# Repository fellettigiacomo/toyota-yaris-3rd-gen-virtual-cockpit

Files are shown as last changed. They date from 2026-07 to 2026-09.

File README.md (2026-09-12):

# Toyota Yaris (3rd Gen / XP130) — Virtual Cockpit





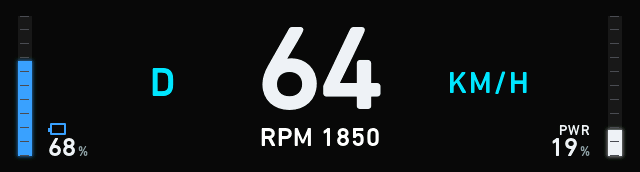
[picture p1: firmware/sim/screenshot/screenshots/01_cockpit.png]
Virtual Cockpit


A from-scratch digital instrument cluster for a 2014 Toyota Yaris Hybrid
(3rd gen / XP130, THS-II NoDSU), driven entirely by the car's own
**reverse-engineered CAN bus** — no dealer tools, no published DBC, no OEM
documentation.

The repository is divided into three main folders:

1. **Reverse-engineering** (`re/`) — a CAN bus sniffer and all the
   documentation, Python tooling and findings used to decode the bus
   signal by signal.
2. **CAN Database (DBC)** (`dbc/`) — the CAN Database with all the decoded
   signals and their translation formulas.
3. **3D Models** (`3d/`) — Fusion360 Project File and 3MF print files to 3d print the enclosure
4. **The dashboard** (`firmware/`) — an LVGL-based instrument cluster
   firmware that decodes the resulting DBC live and drives a physical
   display strip mounted in the car.

> **Safety note.** The firmware only ever *listens* to the vehicle's CAN bus
> (`TWAI_MODE_LISTEN_ONLY` — no transmit, no ACK, per the ESP-IDF driver
> contract). It cannot send commands to the car. That said, this taps a real
> vehicle's diagnostic bus: read the staged bring-up procedure in
> [`re/obd-capture-fw/README.md`](re/obd-capture-fw/README.md) before
> connecting anything to a running car.

## Screens

The cluster cycles through four screens either with the board's physical
**BOOT button**, or by **tapping anywhere on the panel** (presence-only
touch).

### 🏁 Cockpit

Speed, gear (or 0–50 / 0–100 accel timer), RPM/EV state, and two matching
vertical gauges flanking it: HV battery charge on the left, instantaneous
CHG/PWR power flow on the right.

Cockpit

### ⚡ Energy Flow

ENGINE / MOTOR / BATTERY / WHEELS and the four paths between them. Each link
is a dim shaft carrying a bright segment that travels the way the energy
does — red for the engine's mechanical drive, green for anything being
recovered, blue for the pack when it is the one giving.

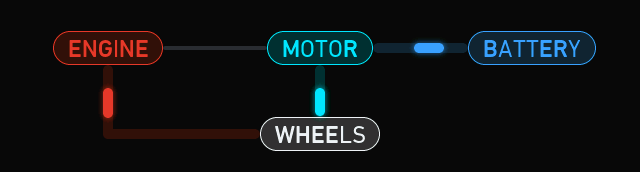
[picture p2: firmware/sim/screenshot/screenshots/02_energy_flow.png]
Energy Flow


### 📊 Efficiency

The session's EV-vs-engine split, drawn as a full-bleed divide of the whole
screen: the electric share fills from the left edge, the engine share holds
the rest, and both percentages hang off the seam between them. Distance and
average speed keep the bottom corners.

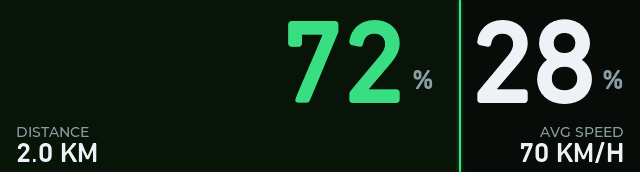
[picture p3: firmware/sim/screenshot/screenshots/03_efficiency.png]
Efficiency


### 📈 G-Meter

Longitudinal and lateral acceleration from the board's own QMI8658 IMU, on a
g-ball where the dot is the acceleration vector — up under power, down under
braking, sideways the way the car is turning — plus the session's four
directional peaks.

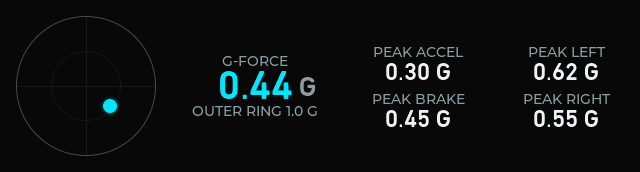
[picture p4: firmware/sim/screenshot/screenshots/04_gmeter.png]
G-Meter


## Hardware

- **Board**: Waveshare ESP32-S3-Touch-LCD-3.49 (ESP32-S3R8, 8 MB PSRAM,
  16 MB flash) — AXS15231B QSPI display, physical panel 172×640 portrait,
  rotated in software to a 640×172 landscape strip.
- **CAN transceiver**: SN65HVD230, wired to OBD-II pins 6 (CAN-H) / 14
  (CAN-L). Full wiring table and GPIO rationale in
  [`re/obd-capture-fw/README.md`](re/obd-capture-fw/README.md).
- **IMU**: the board's onboard QMI8658, on its sensor I2C bus (GPIO47/48,
  address 0x6B) — accelerometer only, for the G-meter screen. Nothing to
  wire: it is already on the board.

## Repository layout

```
.
├── dbc/                     # Reverse-engineered DBC (toyota_yaris_xp130_reversed.dbc)
├── firmware/                # Dashboard firmware (LVGL) + desktop simulator
│   ├── include/             #   board pins, VehicleState struct, LVGL config
│   ├── src/
│   │   ├── ui/               #   screens: cockpit_ui, energy_flow_ui, efficiency_ui, gmeter_ui
│   │   ├── can_decoder.cpp   #   DBC-driven CAN -> VehicleState decode
│   │   ├── imu.cpp           #   QMI8658 accelerometer (G-meter screen)
│   │   └── g_meter.cpp       #   IMU + CAN -> forward/lateral g, axes self-calibrating
│   └── sim/                 #   SDL2 desktop simulator, no board required
└── re/                      # Reverse-engineering workspace
    ├── obd-capture-fw/      #   ESP32-S3 passive CAN sniffer + SD logger
    ├── docs/                #   Signal reverse-engineering notes and findings
    ├── tools/               #   Python scripts used to reverse-engineer the bus
    └── data/logs/           #   Sample real-drive CAN captures (candump format)
```

## Building the dashboard firmware

Requires [PlatformIO](https://platformio.org/) (CLI or VS Code extension).

```sh
cd firmware
pio run                 # build
pio run -t upload       # flash
pio device monitor      # serial console @ 115200
```

No car handy? Build the `demo` environment instead — it sweeps `VehicleState`
with fake data and skips CAN entirely:

```sh
pio run -e demo -t upload
```

## Desktop simulator

Iterate on screen UI without any hardware, replaying a real drive log in an
SDL2 window (macOS, via Homebrew):

```sh
brew install sdl2 cmake
cd firmware/sim
cmake -B build
cmake --build build -j
./build/sim
```

Press SPACE to cycle screens, same as the board's BOOT button. Details and
known rough edges in [`firmware/sim/README.md`](firmware/sim/README.md).

## Building the CAN sniffer (`re/obd-capture-fw`)

```sh
cd re/obd-capture-fw
pio run
pio run -t upload
pio device monitor
```

Logs every frame to SD in `candump`-compatible text, and can stream the same
data live over USB (`STREAM ON` at the serial console) for capture straight
to a PC via `re/tools/usb_stream_logger.py`. Full bring-up order, wiring, and
safety steps in [`re/obd-capture-fw/README.md`](re/obd-capture-fw/README.md).

## Reverse-engineering workflow

1. Capture raw frames with `re/obd-capture-fw` → SD card, `candump` format.
2. Analyze with the scripts in [`re/tools/`](re/tools/) (`id_stats.py`,
   `byte_stats.py`, `decode_dbc.py`, `cross_validate_candidates.py`, …) or
   import into SavvyCAN / `python-can` / `cantools`.
3. Confirmed signals go into [`dbc/toyota_yaris_xp130_reversed.dbc`](dbc/toyota_yaris_xp130_reversed.dbc),
   with methodology and evidence in [`re/docs/signal_findings.md`](re/docs/signal_findings.md)
   and a quick-reference table in [`re/docs/decoded_signals_summary.md`](re/docs/decoded_signals_summary.md).
4. `firmware/src/can_decoder.cpp` decodes the same signals live on
   the dashboard.

Speed, RPM, gear, pedals, EV-drive, HV battery SOC, and the CHG/ECO/PWR
gauge are all confirmed on two independent real-drive logs. HV battery
current/voltage and remaining range are confirmed **absent** from this bus.

## Status

Hobby, single-vehicle reverse-engineering project — signal mappings may not
carry over to other trims/markets/model years. Parts of this repo have not
yet been compiled or run on real hardware (see the caveats in
`re/obd-capture-fw/README.md` and `firmware/sim/README.md`); expect to
iterate on first boot.

## Contributing

Issues and PRs are welcome, especially signal validation on other Yaris
Hybrid units — please note your model year/market if you're confirming or
contradicting a signal in `re/docs/signal_findings.md`.

## License

No license has been chosen yet.

## Acknowledgments

- [pioarduino/platform-espressif32](https://github.com/pioarduino/platform-espressif32)
- [lewisxhe/SensorsLib](https://github.com/lewisxhe/SensorsLib)
- [LVGL](https://lvgl.io/) 8.3
- Waveshare's official ESP32-S3-Touch-LCD-3.49 example code (display/board
  bring-up reference)

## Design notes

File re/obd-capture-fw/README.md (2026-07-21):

# obd-capture-fw

Firmware for the ESP32-S3 (Waveshare ESP32-S3-Touch-LCD-3.49) that passively
sniffs the Toyota Yaris Hybrid (3rd gen / XP130, 2014) OBD-II CAN bus, shows a
live "candump on screen" table on the built-in display, and logs every raw
frame to a microSD card in a format directly importable into SavvyCAN /
python-can / cantools for offline reverse-engineering.

This is step one of the larger virtual-cockpit dashboard project (`../../firmware/`):
Toyota does not publish a DBC for this vehicle, so nothing (EV mode, energy
flow, speed, etc.) can be decoded until the CAN IDs are reverse-engineered
from a capture -- this tool's only job is to capture everything so that can
happen afterwards on a PC.

## Hardware

- **Board**: Waveshare ESP32-S3-Touch-LCD-3.49 (ESP32-S3R8, 8MB PSRAM, 16MB
  flash, silkscreen "Rev1.1"). AXS15231B display (172x640, QSPI), PCF85063
  RTC, onboard microSD slot (SDMMC 1-bit).
- **CAN transceiver**: SN65HVD230 (3.3V, no level shifting needed).

### Wiring

| SN65HVD230 pin | Connect to |
|---|---|
| VCC | 3V3 (expansion header, right column) |
| GND | G (expansion header, right column) |
| TX  | GPIO1 |
| RX  | GPIO2 |
| RS  | GND (always high-speed mode) |
| CANH | OBD-II pin 6 |
| CANL | OBD-II pin 14 |
| (car GND) | OBD-II pin 4 or 5 |

**Important:**
- Leave the SN65HVD230 breakout's onboard 120-ohm termination jumper **open
  / disabled**. The vehicle's CAN bus is already terminated at both ends;
  adding a third 120-ohm resistor degrades signal integrity.
- GPIO1/GPIO2 were chosen from the 22-pin expansion header pins confirmed
  present on this board's silkscreen (0, 1, 2, 3, 4, 5, 19, 20, 38, 39, 40,
  41, 43, 44). Avoided: **GPIO0/3** (boot strapping -- GPIO0 is already wired
  to the BOOT button), **GPIO19/20** (native USB D-/D+ -- this is the same
  USB-C port used for flashing and the serial monitor; wiring anything else
  to these pins conflicts electrically with the USB PHY and will break USB
  communication), **GPIO39/40/41** (used internally by the onboard SD card
  slot), **GPIO43/44** (UART0 / USB-serial bridge), and **SDA/SCL** (GPIO47/48,
  already used internally for the RTC/IMU I2C bus -- also electrically
  incompatible with the transceiver's TX/RX signaling even if it were free).
  GPIO4/GPIO5 are an equally valid alternative pair (also on the header's
  right column) if GPIO1/2 turn out to be inconvenient to wire.
- All onboard peripheral pins (display, RTC, SD) in `include/board_pins.h`
  were extracted directly from Waveshare's own official example code
  (`github.com/waveshareteam/ESP32-S3-Touch-LCD-3.49`), not guessed.

### Physical stop-capture control

There's no touchscreen UI in this tool -- the physical **BOOT button** on the
board is used to safely close the current capture session and start a new
one (drains the SD write queue, closes the file cleanly, writes a `.meta`
sidecar). Touch was intentionally skipped here to avoid depending on the
AXS15231B's proprietary touch protocol for a tool whose only real job is
logging; touch/LVGL is reserved for the later dashboard project.

## Building

Requires [PlatformIO](https://platformio.org/) (CLI or VS Code extension).

```
cd re/obd-capture-fw
pio run              # build
pio run -t upload    # flash
pio device monitor   # serial console (115200 baud)
```

The project uses the [pioarduino](https://github.com/pioarduino/platform-espressif32)
community platform instead of the official PlatformIO `espressif32` platform,
because it ships arduino-esp32 3.x (IDF5-based), needed for the QSPI
`quad_mode` support in `esp_lcd_panel_io_spi_config_t` that the display
driver uses (see `src/WAVESHARE_VENDORED.md`). The official registry
platform was still pinned to an older arduino-esp32 2.0.x core at the time
this was written.

The display is driven via ESP-IDF's `esp_lcd` component and Waveshare's own
panel driver (ported verbatim into `src/axs15231b/`, `src/touch/` -- see
`src/WAVESHARE_VENDORED.md`), the same fix `../../firmware/` uses for the
same panel -- not `GFX Library for Arduino`'s own AXS15231B panel driver,
which produces flicker/split-screen/black-line corruption on this panel over
QSPI (see `src/display_ui.cpp`'s header comment). `GFX Library for Arduino`
is still a dependency, but only for its headless `Arduino_Canvas`
(RAM-only framebuffer + bitmap-font text rendering).

This firmware has **not yet been compiled/tested on real hardware** -- it was
written against Waveshare's official example code and the documented APIs of
`driver/twai.h`/`esp_lcd` (ESP-IDF), `GFX Library for Arduino`, and
`SensorLib` (`lewisxhe/SensorsLib`, the same RTC library Waveshare's own
demos use), but please build it yourself and watch the serial monitor
closely on first boot.

## Setting the clock

The board has no GPS/network time source. Log timestamps use monotonic
`esp_timer_get_time()` deltas regardless, but the *absolute* time in each
session's filename and candump timestamps comes from the onboard PCF85063
RTC, which needs to be set once. Over the serial monitor:

```
SETTIME <unix_epoch_seconds>
```

If the RTC has never been set, sessions still capture correctly, just with
timestamps relative to the ESP32's own boot time (filenames get a
`RTCUNSET` tag instead of a date, and each `.meta` file records
`rtc_valid=0`).

## Live USB streaming (debug / new-feature work without pulling the SD card)

In addition to logging to the SD card, every captured frame can be streamed
live over the same USB-CDC port used for flashing/the serial monitor, in the
same candump text format as the `.log` files. This is a separate fan-out
from `canRxTask` (own queue, own task, see `usb_stream.cpp`), so a slow or
absent PC-side reader can never affect SD logging or drop frames from the
capture.

Over the serial monitor:

```
STREAM ON    # raw candump lines start flowing over the port
STREAM OFF   # back to the normal [status]/[main]/... console output
```

While streaming is on, the periodic `[status]` line is suppressed so the
port carries pure candump lines; occasional other firmware messages (e.g. a
bus-off warning) can still interleave, so anything reading the stream should
just ignore lines that don't match the candump shape.

To capture straight to a file on a PC, use
[`../tools/usb_stream_logger.py`](../tools/usb_stream_logger.py)
(`pip install pyserial`):

```
python3 ../tools/usb_stream_logger.py /dev/ttyACM0
python3 ../tools/usb_stream_logger.py /dev/ttyACM0 ../data/logs/bench_test.log --settime
```

It sends `STREAM ON`, writes every valid candump line to the output file
(filtering out any non-candump firmware messages), and sends `STREAM OFF` +
closes cleanly on Ctrl+C. The resulting file is byte-for-byte the same
format as an SD `.log`, so it drops straight into `../tools/parse_log.py`,
SavvyCAN, `python-can`, or `cantools`.

## Bring-up order (do this in order, do not skip ahead)

1. **Display/SD/RTC only.** Flash and check the serial monitor + screen with
   nothing connected to GPIO1/2 yet. Confirm the stats bar renders, the SD
   card mounts (`SD:` shows free space instead of `NONE`), and the RTC
   responds.
2. **CAN bench test, no vehicle.** Wire the SN65HVD230 to GPIO1/2 (RS to
   GND, termination jumper open) but do **not** connect CANH/CANL to the car
   yet. The TWAI driver runs in `TWAI_MODE_LISTEN_ONLY` -- per the ESP-IDF
   documentation this mode does not transmit or ACK anything on the bus, so
   it is safe to bring up in isolation. Confirm no bus errors are reported
   with nothing connected.
3. **Ignition-accessory only, engine off.** Connect CANH/CANL to OBD-II pins
   6/14 (and ground to pin 4 or 5). Before powering the transceiver, check
   with a multimeter that the bus looks sane (idle CAN-H/CAN-L both settle
   near 2.5V; do this with the transceiver disconnected). Turn the key to
   accessory/on (engine off) and watch the error/bus-off counters on the
   stats bar closely for the first few minutes.
4. **Engine running.** Only once step 3 looks clean, start the engine and
   let a full capture session run.
5. **Stop and pull the card.** Press BOOT to cleanly close the session, then
   remove the SD card and import `/CANLOGS/session_NNNN_*.log` into SavvyCAN,
   `python-can`, or `cantools`.

## Log format

Each `.log` file is plain SocketCAN-`candump`-compatible text, one frame per
line:

```
(1720098765.123456) can0 1d0#0011223344556677
```

- Timestamp: seconds.microseconds (RTC epoch + monotonic delta if the RTC is
  set, otherwise relative to boot).
- `can0` is a literal label (not tied to actual wiring) -- this is what
  generic candump-log importers expect.
- CAN ID: lowercase hex, zero-padded to 3 digits (standard/11-bit) or 8
  digits (extended/29-bit).
- Data: lowercase hex, 2 characters per byte, byte count implied by DLC.
- RTR frames are logged as `id#R` with no data bytes.

A sidecar `.meta` file (same base name) holds session metadata (frame count,
bus-error/bus-off counts, RTC validity, bitrate) -- deliberately **not**
inlined into the `.log` file, so the log stays 100% strict-format and safe
to feed straight into SavvyCAN/python-can/cantools without pre-processing.

## Notes / known limitations

- **No second CAN node was available to test the listen-only mode's
  passivity** (e.g. by deliberately inducing a bus error and watching for any
  dominant bits with a scope). The firmware relies on `TWAI_MODE_LISTEN_ONLY`
  behaving exactly as ESP-IDF documents it (fully passive, no ACK, no
  transmission). Do the ignition-accessory-only bring-up step above before
  ever running with the engine on, and stop immediately if bus errors climb.
- Data written since the last periodic `fsync` (every 5s, see
  `SD_SYNC_INTERVAL_MS` in `include/app_config.h`) can be lost on abrupt power
  loss. Always use the BOOT button to stop a session cleanly before
  disconnecting power.
- Bus load % is an approximation (fixed ~47 bits of framing overhead per
  frame, ignoring CAN bit-stuffing).
- This firmware has not been compiled yet (see "Building" above). The display
  driver was ported from `../../firmware/`'s already-hardware-verified
  `esp_lcd`-based approach (see `src/display_ui.cpp`'s header comment), but
  that specific port has not itself been tested on this project's hardware --
  watch the panel closely on first boot.

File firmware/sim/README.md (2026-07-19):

# Desktop simulator

Runs the real cluster UI (`src/ui/*`) in an SDL2 window on your Mac, fed by
the same real-drive-log replay the `pio run -e demo` firmware build uses
(`can_decoder.cpp` + `demo_log_data.cpp`, unmodified) -- no ESP32 board, no
flashing. It does **not** exercise `display_driver.cpp` or anything
ESP-IDF/hardware-specific; that stays firmware-only. The BOOT-button screen
switch (`screen_nav.cpp`) is simulated via the spacebar, and the panel's
tap-anywhere touch switch (`touch_nav.cpp`) via a left click anywhere in
the window.

## Build

```sh
brew install sdl2 cmake
cd firmware/sim
cmake -B build
cmake --build build -j
./build/sim
```

First build takes a little longer since CMake fetches LVGL 8.3.11 from
GitHub (same version `platformio.ini` pins for the firmware).

If `cmake -B build` can't find SDL2 (rare, usually only if Homebrew isn't on
your default `PATH`/`CMAKE_PREFIX_PATH`), retry with:

```sh
cmake -B build -DCMAKE_PREFIX_PATH=$(brew --prefix)
```

## Use

- Press SPACE, or click anywhere in the window, to cycle screens -- the
  spacebar stands in for the board's BOOT button (GPIO0), the click for a
  tap on the touch panel, both drive the same cycle on real hardware.
- The drive log loops automatically (~5.7 minutes/lap) and includes real
  EV/regen/charge/cruise/kick-down transitions, so the energy-flow arrows
  should visibly change direction and color as it plays.
- Close the window (or Cmd+Q) to quit.

## Caveat

This was written and reviewed by hand against LVGL 8.3's documented API and
this repo's own `display_driver.cpp` (for the LVGL display-driver wiring)
but was **not compiled or run** in the environment it was written in (no
SDL2/CMake toolchain, no Mac, no display available there). If `cmake`/the
build fails, that's expected to be entirely fixable -- it just hasn't been
exercised yet. The most likely rough edges, in rough order of likelihood:

- The `LV_CONF_PATH`/`LV_CONF_INCLUDE_SIMPLE` wiring in `CMakeLists.txt` was
  checked against LVGL's actual `env_support/cmake/custom.cmake` for v8.3.11,
  not assumed -- but CMake variable-scoping subtleties around
  `FetchContent_MakeAvailable` are exactly the kind of thing that looks right
  on paper and isn't.
- `SDL_PIXELFORMAT_RGB565` streaming-texture support should be universal on
  macOS's default (Metal-backed) SDL2 renderer, but hasn't been confirmed.

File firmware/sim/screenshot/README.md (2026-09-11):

# Screenshot renderer

Regenerates the screenshots the top-level README shows, straight from the real
LVGL UI — no SDL, no window, no board. Every pixel comes out of the same
`build()` / `update()` the firmware calls, so these frames are the cluster,
not a mockup of it.

```sh
cd firmware/sim/screenshot
./render.sh
```

That builds, plays the scenes, and writes `screenshots/*.png` at the panel's
native 640×172.

**It takes a couple of minutes**, most of it the efficiency scene. The UI
modules integrate against `millis()`, so the scenes run in real time rather
than fast-forwarded — and the efficiency screen's EV share is weighted by
distance, so the only way to reach a given split with a plausible trip behind
it is to actually drive the distance.

## What gets rendered

| File | Scene |
|---|---|
| `01_cockpit.png` | 64 km/h in D, engine running, 68% SOC, 19% PWR |
| `02_energy_flow.png` | Hybrid drive — engine to the wheels, pack assisting through the motor, one link idle |
| `03_efficiency.png` | ~2 km covered, 72% of it electric |
| `04_gmeter.png` | Trail-braking into a right-hander, after a drive that fills the peaks |

## Notes on the scenes

The scenes are scripted `VehicleState` sequences, not canned frames, so they
have to satisfy the same logic the car does:

- **The cockpit is rendered first, and never from a standstill.** `AccelTimer`
  arms itself at zero speed, so a scene that jumped from 0 to 64 km/h would
  latch a bogus 0–50 result and replace the gear letter with it.
- **The G-meter scene has to earn its axes.** `screenshot.cpp` provides its own
  `Imu::` rather than linking `src/imu.cpp`, and it deliberately does *not*
  hand the calibration pre-aligned axes: it synthesizes what a real
  accelerometer would have measured and rotates it through an arbitrary
  mounting (yaw 35°, pitch 20°, roll 10°). The scene then drives a standstill,
  a launch, braking and both corners so `g_meter.cpp` can find level, learn
  which way is forward, and fill the peak tiles — exactly as it would in the
  car.
- **Screens are cycled through the real BOOT-button path**, debounce included,
  rather than by reaching into `AppUi`'s internals.

This is why the renderer is worth having beyond documentation: it exercises
the parts that are otherwise only testable in a moving car. It has already
caught a real bug — the G-meter's level capture was being tilted by braking to
a halt, which showed up here long before the code reached a vehicle.

## Requirements

CMake ≥ 3.16, a C++17 compiler, and Python 3 (standard library only — the
converter uses `zlib` and `struct`). LVGL 8.3.11 is fetched automatically,
the same version `platformio.ini` pins for the firmware and `../CMakeLists.txt`
uses for the simulator.

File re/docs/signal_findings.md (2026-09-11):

# Toyota Yaris Hybrid XP130 (2014, THS-II NoDSU) — CAN bus signal findings

Full methodology and validation evidence behind the signals in
[`toyota_yaris_xp130_reversed.dbc`](../../dbc/toyota_yaris_xp130_reversed.dbc).
For a compact table, see [`decoded_signals_summary.md`](decoded_signals_summary.md).

## Capture setup

- **Tap point**: the factory head-unit connector (28-pin, p/n `90980-12555`),
  pins 9 (CAN-H) / 10 (CAN-L), 500 kbps — **not** the OBD-II diagnostic port.
  This is the same point where the aftermarket Simplesoft CAN-bus box
  normally taps in; the message set seen here (`SPEED`, `RPM`, `GEAR`,
  `BRAKE`, `TURN_SIGNALS`, `ODOMETER`, …) matches what's expected on the
  main HS-CAN bus, so this connector is treated as the same logical bus, not
  a separate/richer one.
- **Logs**: two independent real-drive captures, `session_0044.log` (~430s,
  ESP32 in place of the Simplesoft box) and `session_0047.log` (~440s, ESP32
  inline between the Simplesoft box and the car). A signal is only marked
  "confirmed" once its behaviour reproduces on both.
- **Reference DBCs**: `toyota_nodsu_hybrid_pt_generated.dbc` from
  `BogGyver/opendbc` (branch `tesla_unity_dev`), cross-checked against the
  Prius/Camry/Highlander hybrid variants and `commaai/opendbc` upstream.
  None of these define SOC, range, or fuel — those come from Prius-community
  reverse-engineering docs (EAA-PHEV wiki, PriusChat) and original analysis.
- **Toolchain**: the scripts in [`../tools/`](../tools/) plus `cantools` for
  strict DBC-based decoding. `cross_validate_candidates.py` and
  `find_word16_candidates.py` implement the cross-log check described above.

## Confirmed signals

| Signal | ID | Field | Formula |
|---|---|---|---|
| Gear (P/R/N/D/B) | `0x127` | `GEAR` | 4-bit enum, byte5 high nibble |
| Vehicle speed | `0x0B4` | `SPEED` | `(byte5<<8\|byte6) * 0.01` km/h |
| Engine RPM | `0x1C4` | `RPM` | signed 16-bit `* 0.78125` rpm |
| Accelerator pedal | `0x245` | `GAS_PEDAL` | `byte2 * 0.005` (0–1 = 0–100%) |
| ICE running (bit) | `0x245` | `ICE_RUNNING` | byte3 bit4 |
| Brake pressed (bit) | `0x230` | `BRAKE_PRESSED` | single bit |
| Turn signals | `0x614` | `TURN_SIGNALS` | 2-bit enum + hazard bit |
| Odometer (total) | `0x611` | `ODOMETER` | 20-bit, km/miles unit flag |
| Ambient temperature | `0x442` | `AMBIENT_TEMP` | `byte0 - 40` = °C |
| HV battery SOC | `0x4A7` | `BATTERY_SOC` | `byte2 * 0.5` = % |
| EV drive (bit) | `0x498` | `EV_DRIVE` | byte5 bit7 |
| CHG/ECO/PWR indicator | `0x247` | `HSI_VALUE` / `HSI_ZONE` | see below |

**Gear** — validated across both logs: session_0044 shows a clean
P(0)→R(1)→D(3) sequence with `SPEED` and `BRAKE_PRESSED` transitions lining
up exactly with each shift; session_0047 adds N and a full end-of-drive
cycle through all five states including B (Engine Brake). `CAR_MOVEMENT`
(byte4 of the same message, signed, oscillates ±) is a separate field, not
part of the gear value.

**Speed / RPM** — inherited from opendbc, reconfirmed with `cantools`
against real 0→60→0 kph and idle/rev profiles. `WHEEL_SPEEDS` (0x0AA) from
opendbc is not present on this bus.

`SPEED`'s 0.01 kph scale is cross-validated against the odometer, which is
the one distance reference on board that regulation requires to be
*accurate* (unlike the speedometer — see below). Taking the exact instants
`0x611`'s `ODOMETER` ticks over a whole kilometre, the interval between the
first and last tick in session_0044 is exactly 2 km; integrating the decoded
`0x0B4` speed over that same interval gives 2.0001 km, i.e. **+0.01%**. The
method's own uncertainty is ±0.82%, set by `0x611`'s 1 Hz rate (each tick's
instant is only known to ±1 s). session_0047 never crosses two whole-km
boundaries, so no exact interval can be isolated there.

**Indicated vs. true speed** — the car's own speedometer reads *higher* than
`SPEED`: roughly +10 km/h at an indicated 140 against a true 130 on the
vehicle this was developed on (a single needle reading, so call it +5..+15).
This is deliberate and regulatory, not a decode error. UNECE R39 requires
that the indicated speed never be *lower* than the true speed and caps the
excess at 10% + 4 km/h, so manufacturers bias the cluster upward to stay
compliant across tyre wear, optional tyre sizes and temperature. At a true
130 km/h the legal window is 130–147.

The biased value is computed inside the instrument cluster and is **not**
broadcast: no field on this bus carries it. Four independent speed-carrying
fields all agree with `0x0B4` to within 0.5% across the full 0–63 km/h range
the logs cover — `0x2A4` byte[0:2] (Δ mean 0.00 km/h), `0x610` byte[2]
(1.0001×kph, R²=0.9996) and `0x498` byte[3] (0.9951×kph, R²=0.9957) — and
the odometer check above anchors the scale absolutely. A GPS comparison on
the road matches the decoded value as well.

No correction is applied in firmware, on purpose: `SPEED` is the true speed,
which is what the odometer, GPS and the other bus fields all agree on.
Matching the cluster instead would mean modelling its bias (`indicated =
k × true + c`), and on this car the cluster is an **analog needle** — a
driver reads it to ±3 km/h at best, and any photo-based calibration is
dominated by a systematic parallax error that repeating measurements cannot
average away. Chasing a ~5% correction whose own uncertainty is a few km/h
would add error rather than remove it.

**Accelerator / ICE running** — `GAS_PEDAL` ranges 0–35% observed, tracking
the accelerate/coast pattern of city driving. `ICE_RUNNING` agrees with
`RPM > 50` 98–99% of the time across both logs and is cleaner (no threshold
tuning needed).

**Brake pressed** — transitions line up exactly with gear shifts and speed
changes (brake held at standstill around each shift).

**Turn signals** — all three states (left/right/none) observed with
multi-second durations consistent with real indicator usage.

**Odometer** — confirmed as the *total* odometer (99552→99555 km over the
log), not remaining range; `UNITS` flag correctly reads km.

**Ambient temperature** — the only near-constant byte in the low-frequency
climate message family (`0x440`/`0x442`/`0x44D`/`0x45C`); raw values differed
between the two capture days (77 vs 67 → 37 °C vs 27 °C) and the scale was
confirmed against the actual outside temperature on each day. This is
outside air temperature, not engine/coolant temperature.

**HV battery SOC** — byte[2] of `0x4A7`, range 108–143 raw → 54.0–71.5%,
matching the real THS-II NiMH operating band (~40–80%). A SOC is the
*integral* of power flow, so it barely correlates with the accelerator at
zero lag; it was found by scoring each value *change* against expected
battery physics instead (discharge during EV driving, charge during ICE-on
or regen) rather than by instantaneous correlation. Physics checks out on
both logs: flat while parked, steady climb during stationary ICE warm-up
charging, slow decline through every EV stretch, recovery through every
ICE-on/regen stretch, never wraps. The 0.5%/bit scale matches the known
Techstream/Prius-Gen2 convention but has not been checked against a
reference tool reading.

**EV drive** — byte5 bit7 of `0x498`. On only while the vehicle moves with
the ICE stopped (pure electric propulsion); off at standstill even with the
ICE off, and off while driving with the ICE running. Matches the dash EV
indicator's semantics exactly (100% agreement with the moving+ICE-off state
across both logs). Two redundant "ICE stopped" bits were also found:
`0x49C` byte5 bit6 and `0x4AD` byte3 bit6.

**CHG/ECO/PWR indicator (Hybrid System Indicator)** — the gauge needle
position is broadcast directly on `0x247` (42.5 Hz, companion message to
`GAS_PEDAL`), no synthesis needed. `HSI_VALUE` (byte1) is the needle
position in percent of scale: 0 at standstill, +30..+47 at steady cruise
(the test that rules out this being just a copy of accelerator demand —
cruise needs sustained power even with a near-zero acceleration signal),
up to +86/+94 under moderately hard acceleration, negative while
coasting/braking with a hard clamp at exactly -100 (full CHG). `HSI_ZONE`
(byte0) carries the sign (12=drive/positive, 15=charge/negative,
4=zero-in-gear, 6=P/R). `HSI_GEAR_FLAG` (byte2) is 50 in forward gears,
255 in P/R.

**The sign lives in `HSI_ZONE`, not in `HSI_VALUE`'s byte.** The two sides
of the gauge use different encodings of byte1 and their raw ranges overlap,
so the byte on its own is ambiguous:

| Zone | Meaning | byte1 encoding | Raw seen in logs |
|---|---|---|---|
| 12 | ECO/PWR (positive) | unsigned magnitude, sweeps past 155 | 0–94 |
| 15 | CHG (negative) | two's complement, clamped at -100 | 156–255 (= -100..-1) |
| 4 | zero in gear | always 0 | 0 |
| 6 | P/R, gauge inactive | always 0 | 0 |

The zone/value correlation is exact across both sessions (n=32779, zero
exceptions), which is what makes it usable as the sign source. An earlier
firmware revision instead inferred the sign from byte1 alone (raw≥156 ⇒
negative, anchored on the confirmed CHG floor). That works for everything
in these two calm-driving logs but breaks on the car under full throttle:
the PWR sweep runs past 155, so a hard-PWR raw was read as a large negative
and the bar swung to CHG. On-car testing confirmed the flip; the decoder
now branches on `HSI_ZONE`.

**The four-zone table above describes the logs, not the encoding.** A later
on-car drive with hard acceleration reported `HSI_ZONE` values of 8, 9 and
14 as well — driving neither capture session contains. So 4/6/12/15 is
exhaustive for these logs and incomplete for the car, and what byte0 encodes
beyond the sign is still open. The firmware therefore reads *every* zone but
15 as an unsigned positive magnitude (15 being the only zone ever observed
carrying a negative value) rather than falling back to the DBC-nominal
signed read, and carries a temporary byte0 survey — frame count and raw
min/max per zone, dumped over serial when it learns something new — to be
removed once the encoding is known and the zones can be listed explicitly.

On the display, the PWR side is shown halved (`PWR% = raw/2`) because the
ECO/PWR boundary (raw≈100) is only the midpoint of the real gauge's PWR
sweep, not its top — so full PWR ≈ raw 200 reads 100%. That the raw value
does climb past 155 under full throttle (rather than clamping at +100 like
the CHG side does at -100) is exactly what the false-CHG flip demonstrated,
and it is consistent with this halved scaling.

## Strong hypotheses (semantics solid, exact scale unconfirmed)

| Signal | ID | Field | Notes |
|---|---|---|---|
| Brake pedal (analog) | `0x224` | `BRAKE_VALUE` | 16-bit, strongly correlated with the brake bit |
| Coolant temperature | `0x618` | `TEMP_RAW` | warm-up curve to plateau; scale guess `*0.375` ≈ 90 °C |
| Second temperature (oil/CVT/HV pack?) | `0x3B9` | `TEMP2_RAW` | correlates with elapsed time and coolant temp |
| Longitudinal accel/torque demand | `0x320` | `ACCEL_DEMAND` | signed, positive on acceleration, negative on braking/coast |
| Fuel consumption counter | `0x3A0` | `FUEL_COUNTER_RAW` | decrements with ICE-on runtime, **not** a tank-level gauge |

**Brake analog value** — byte[4:6] of `0x224` (~41 Hz, same rate as
`SPEED`/`BRAKE_PRESSED`, likely the same ECU). Median 0 while released vs.
median 62 while pressed (n=12027/5731); 99.99% of released samples are ≤5,
84% of pressed samples are >5. A single release event shows a smooth
continuous decay over ~700 ms, consistent with an analog pressure or pedal
position rather than a second bit. Exact units and full-scale range are not
confirmed (max observed 537, slightly above the 0–511 9-bit range opendbc's
unrelated `BRAKE_MODULE`/0x226 template would suggest — that ID is absent
from this bus).

**Coolant temperature** — byte[3] of `0x618`, part of a low-frequency
(~0.1 Hz) "combination meter" message family (`0x610`-`0x615`,
`0x618`-`0x61C`). Climbs from 0 at cold start to a plateau around 230–240 by
t≈350–430s, matching a textbook engine coolant warm-up curve reaching
thermostat-regulated temperature after ~5 minutes. `temp_C ≈ raw * 0.375`
places the plateau at a plausible 90 °C but is an unverified guess, not a
reference-thermometer calibration; could equally be transmission/CVT fluid.

**Second temperature signal** — byte[0] of `0x3B9` (dlc=3, only this byte
active, ~1 Hz). Climbs smoothly to a plateau late in the drive on both logs,
correlating strongly with elapsed time (r=0.945/0.968) and with the coolant
curve above (r=0.950/0.969), including a shared inflection point. Weak
correlation with instantaneous RPM (r≈-0.1) rules out a fast-responding
sensor and points to a larger thermal mass — candidates: engine oil,
CVT/transaxle fluid, or HV battery pack. Plateau value differs between the
two logs (173 vs 160), unlike a thermostat-regulated coolant signal, which
fits a less tightly-regulated mass. No scale proposed.

**Longitudinal accel/torque demand** — byte[4] of `0x320` (signed, ~20 Hz):
positive under acceleration (+10..+31 with pedal), negative while
braking/coasting (-8..-48), ~0 at rest and at steady cruise — this last
point is what rules it out as HV battery current, since current should stay
nonzero at cruise. byte[7] is the same signal with a constant +42 offset;
byte[5] is a `{0,8}` flag active only at standstill. Scale unconfirmed
(plausible ~0.02–0.05 m/s² per LSB).

**Fuel consumption counter** — byte[7] of `0x3A0`, the only active byte in
an otherwise all-zero message, 10 Hz. Decrements track ICE-on runtime
(~1 unit per 20–25s of engine running, consistent to ~7% across both logs),
not wall-clock time or distance, which rules out both "fuel level" (a 36 L
tank on this scale would imply an impossible 50+ L/h burn rate) and
"distance to empty". Best read as a high-resolution fuel-consumed counter,
quantum ≈10–30 mL — most likely the low byte of a wider register, since a
wrap 255→0 has not yet been observed (would need a ≥30 min log to confirm).
Use it for instantaneous consumption, not as an absolute level.

## Present but not independently validated

Inherited from opendbc at their documented layout; message exists at the
expected ID but the specific bits were not exercised during capture:

- `0x620 SEATS_DOORS` — door open / seatbelt bits (seatbelt toggled 0/1;
  doors never opened during the drive)
- `0x622 LIGHT_STALK` — headlight/fog/auto-high-beam bits (low
  beam/parking light toggled, plausible)
- `0x399 PCM_CRUISE_SM` — cruise control state (all-zero, never engaged)
- `0x3B7 ESP_CONTROL` — traction/VSC disable, brake lights (all-zero, no
  VSC/TC intervention during this calm drive)

## Ruled out

Documented so these aren't re-investigated:

- **`0x4A8` byte2 top-3-bits** — looked like a battery-bar level; it's a
  cyclic counter that wraps every 60–100s, physically incompatible with an
  HV battery.
- **`0x4A2` byte3/byte5** (`CHASSIS_BRAKE2`) — anti-correlates with the
  accelerator/braking pattern strongly enough to look like battery power at
  first, but correlates even more strongly with the confirmed brake analog
  signal (`0x224`) and with `SPEED` (which battery power shouldn't track) —
  almost certainly a second ABS/VSC brake telemetry pair, not SOC.
- **`0x612` byte5, `0x619` byte6, `0x63B` byte6** — unstable trends whose
  correlation sign flips between the two logs, or fixed-period counters
  (`0x63B` increments every ~25.5s regardless of driving state) — heartbeat/
  counter artifacts, not physical signals.
- **`0x4AC` byte6** — free-running 4.5s-on/4.5s-off square wave (9.0s
  period), present identically in every log. Not an event/status signal.

## Confirmed absent from this bus

Not obtainable by passive listening on this connector:

- **Remaining driving range (km)** — only the total odometer exists;
  likely computed inside the instrument cluster and never broadcast.
- **HV battery current / voltage / temperature** — no broadcast found;
  the Prius-style diagnostic IDs (`0x03B`/`0x3CB`/`0x529`) are absent on
  this platform. Would require solicited UDS requests to the battery ECU.

## Architecture notes

Signals `0x498`–`0x4AF` are an undocumented Toyota hybrid-powertrain
telemetry family — opendbc's `toyota_2017_ref_pt.dbc` names the same ID
range `ENG1D50`..`ENG1D60`, opaque data-recorder frames from the `CGW`
(Central Gateway) node, absent on non-hybrid Toyota models. This is where
SOC and hybrid status live. With SOC, EV-drive, ICE-running and the HSI
power-demand signal, the aftermarket Simplesoft box's "OilElectricityInfo"
energy-flow display (3-bit battery level, hybrid flag, 6 flow-direction
flags) can be fully reconstructed from passive listening alone — no active
diagnostic polling needed, despite the ~10s the box's screen takes to load
(most likely just app initialization, not a diagnostic round-trip).

## Open questions

1. **SOC scale** (`0.5%/bit`) is a known Toyota/Techstream convention, not
   yet checked against a reference tool reading.
2. **Fuel counter wrap** (`0x3A0` byte7) — needs a ≥30 min log to observe
   the predicted 255→0 rollover and confirm it's the low byte of a wider
   register.
3. **`0x612` byte5** — a slow random walk centered on 128 (±16) with a
   byte1 heartbeat bit; excluded as SOC (no charge/discharge physics) but
   not identified. Possibly 12V-battery current with an offset. Low
   priority.
4. **`0x4AE` byte7** — rises slowly (72→75) in both logs; a weak,
   unconfirmed candidate for HV battery/inverter temperature.
5. **CHG/PWR positive ceiling** — the true raw value at 100% PWR is still
   unverified; needs a capture that includes hard acceleration into the
   PWR zone (see the CHG/ECO/PWR writeup above).

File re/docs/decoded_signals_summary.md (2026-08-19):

# Toyota Yaris Hybrid XP130 (2014, THS-II NoDSU) — Decoded CAN Signals

Quick reference for what has been reverse-engineered on this vehicle's CAN
bus. Full methodology and validation evidence: [`signal_findings.md`](signal_findings.md).
Machine-readable definitions: [`../../dbc/toyota_yaris_xp130_reversed.dbc`](../../dbc/toyota_yaris_xp130_reversed.dbc).

Capture point: factory head-unit connector (28-pin, CAN-H/CAN-L), 500 kbps.
Validated on two independent real-drive logs (~430s and ~440s).

## What we found

- Every gauge-relevant signal on the dash is decoded: speed, RPM, gear, turn
  signals, accelerator, brake, ambient temperature, and the CHG/ECO/PWR
  power-flow needle.
- The HV battery **SOC** and an explicit **EV-drive bit** are plain passive
  broadcasts — no active diagnostic polling needed.
- A high-resolution **fuel-consumption counter** exists, but it is not a fuel
  level gauge — no absolute tank level is available on this bus.
- HV battery current/voltage and remaining driving range are confirmed
  absent from this bus; not obtainable by passive listening.

## Confirmed signals (validated on 2 independent logs)

| Signal | CAN ID | Field | Formula / meaning |
|---|---|---|---|
| Vehicle speed | `0x0B4` | `SPEED` | `(byte5<<8\|byte6) * 0.01` km/h |
| Engine RPM | `0x1C4` | `RPM` | signed 16-bit `* 0.78125` rpm |
| Gear (P/R/N/D/B) | `0x127` | `GEAR` | 4-bit enum, all 5 states observed |
| Accelerator pedal | `0x245` | `GAS_PEDAL` | `byte2 * 0.005` (0–1 = 0–100%) |
| ICE running (bit) | `0x245` | `ICE_RUNNING` | byte3 bit4, 98–99% agreement with RPM>50 |
| Brake pressed (bit) | `0x230` | `BRAKE_PRESSED` | single bit |
| EV drive (bit) | `0x498` | `EV_DRIVE` | byte5 bit7, on only while moving with ICE off |
| HV battery SOC | `0x4A7` | `BATTERY_SOC` | `byte2 * 0.5` = % (observed 54–71.5%, matches THS-II operating band) |
| CHG/ECO/PWR indicator | `0x247` | `HSI_VALUE` / `HSI_ZONE` | % of gauge scale; **the sign comes from `HSI_ZONE`, not from byte[1]** — zone 12 = PWR side, byte[1] unsigned (sweeps past 155 at full throttle), zone 15 = CHG side, byte[1] two's complement clamped at -100 (raw 156), zones 4/6 = zero. The two sides' raw ranges overlap, so inferring the sign from byte[1] alone flips full PWR into full CHG. Display halves the raw value on the PWR side (PWR% = raw/2, CHG unchanged) — the ECO/PWR boundary is only the midpoint of the real gauge's PWR sweep, not its top. See `signal_findings.md` |
| Turn signals | `0x614` | `TURN_SIGNALS` | 2-bit enum (+ hazard bit) |
| Odometer (total) | `0x611` | `ODOMETER` | 20-bit, km/miles unit flag — NOT remaining range |
| Ambient/outside temperature | `0x442` | `AMBIENT_TEMP` | `byte0 - 40` = °C, scale confirmed against real readings; not shown on the cluster (outside air temp, not engine/coolant temp) |

## Strong hypotheses (semantics solid, exact scale/units not fully confirmed)

| Signal | CAN ID | Field | Notes |
|---|---|---|---|
| Brake pedal (analog pressure/position) | `0x224` | `BRAKE_VALUE` | 16-bit, strongly correlated with brake bit |
| Coolant temperature | `0x618` | `TEMP_RAW` | warm-up curve to plateau; scale guess `*0.375` ≈ 90°C |
| Second temperature (oil/CVT/HV pack?) | `0x3B9` | `TEMP2_RAW` | correlates with elapsed time and coolant temp |
| Longitudinal accel/torque demand | `0x320` | `ACCEL_DEMAND` | signed, positive on acceleration, negative on braking/coast |
| Fuel consumption counter | `0x3A0` | `FUEL_COUNTER_RAW` | decrements with ICE-on runtime, NOT a tank-level gauge; likely low byte of a wider register |

## Present but not independently validated (inherited from opendbc, message exists at expected layout)

- `0x620 SEATS_DOORS` — door open / seatbelt bits
- `0x622 LIGHT_STALK` — headlight/fog/auto-high-beam bits
- `0x399 PCM_CRUISE_SM` — cruise control state
- `0x3B7 ESP_CONTROL` — traction/VSC disable, brake lights

## Ruled out / excluded (documented so they aren't re-investigated)

- `0x4A8` byte2 top-3-bits — looked like a battery bar level: cyclic counter (wraps every 60–100s)
- `0x4A2` `CHASSIS_BRAKE2` — looked like battery power: actually a second brake/ABS-VSC signal
- `0x612` byte5, `0x619` byte6, `0x63B` byte6 — unstable or heartbeat-like, not physical signals
- `0x4AC` byte6 — free-running 4.5s-on/4.5s-off oscillator (9s period), not an event/status signal

## Confirmed absent from this bus (not obtainable by passive listening)

- **Remaining driving range (km)** — only the total odometer exists; likely computed inside the instrument cluster only
- **HV battery current / voltage / temperature** — no broadcast found; Prius-style diagnostic IDs (0x03B/0x3CB/0x529) are absent on this platform; would require solicited UDS requests to the battery ECU

## Architecture note

Signals `0x498`–`0x4AF` are an undocumented Toyota hybrid-powertrain telemetry
family (matches opendbc's opaque `ENG1D5x`/`CGW` gateway frames, absent on
non-hybrid Toyota models) — this is where SOC and hybrid status live. With
SOC, EV-drive, ICE-running and the power-demand signal above, the aftermarket
Simplesoft CAN-bus box's energy-flow display can be fully reconstructed from
passive listening alone, no active diagnostics needed.

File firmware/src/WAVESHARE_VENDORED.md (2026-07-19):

# Vendored from Waveshare's official example

`axs15231b/`, `touch/`, `lcd_bl_bsp/`, `i2c_bsp.c`, `i2c_bsp.h`, and
`user_config.h` in this directory are copied verbatim (not hand-retyped) from
Waveshare's official ESP32-S3-Touch-LCD-3.49 example bundle
(`Arduino/10_LVGL_V9_Test/src/`, plus its `user_config.h`) -- the same
hardware this board's `board_pins.h` cites.

Why: Arduino_GFX's generic AXS15231B driver does not drive this panel
correctly over QSPI (see `display_driver.cpp`'s header comment for the full
explanation -- in short, this panel has no row-seek command in QSPI mode and
requires the *entire* frame to be written sequentially every refresh).
Waveshare's own `esp_lcd`-based driver handles this correctly and is proven
to work on real hardware; porting it byte-for-byte (rather than
re-implementing it) avoids re-introducing the same class of bug.

`display_driver.cpp` is this project's own code, gluing the vendored panel
driver to LVGL and to `cockpit_ui`/`can_decoder`. Touch
(`touch/esp_lcd_touch.*`, the touch-related parts of `axs15231b/*` --
`esp_lcd_touch_new_i2c_axs15231b()` and friends -- and the I2C touch device
handle in `i2c_bsp.c`) is still not wired up or called anywhere in this
project: `../touch_nav.cpp` talks to the same AXS15231B touch die directly
over plain Arduino `Wire`, replicating the vendored driver's read protocol
byte-for-byte (read, not called -- see that file's header comment for why:
mainly to avoid depending on the exact `esp_lcd_panel_io_i2c` API shape of
whatever ESP-IDF minor version this Arduino core pins, which has changed
across IDF releases, unlike `Wire`). `user_config.h` is only needed to
satisfy `i2c_bsp.c` and `lcd_bl_bsp/lcd_bl_pwm_bsp.c`'s own `#include`; this
project's actual pin/task config lives in `include/board_pins.h` and
`include/app_config.h`, not here -- the two headers don't conflict (checked:
no shared macro names appear in translation units that include both).

Do not hand-edit these files piecemeal; if Waveshare updates their example,
re-copy wholesale from the new version instead of patching around drift.

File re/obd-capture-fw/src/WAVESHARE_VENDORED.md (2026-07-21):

# Vendored from Waveshare's official example

`axs15231b/` and `touch/` in this directory are copied verbatim (not
hand-retyped) from Waveshare's official ESP32-S3-Touch-LCD-3.49 example
bundle (`Arduino/10_LVGL_V9_Test/src/`) -- identical to the copies in
`../../firmware/src/`, duplicated here rather than shared because each
PlatformIO project vendors its own copy of third-party code (see that
directory's own `WAVESHARE_VENDORED.md` for the full rationale).

Why: this project originally drove the display via Arduino_GFX's generic
AXS15231B driver (`Arduino_ESP32QSPI` + `Arduino_AXS15231B`, SPI2_HOST),
which produced flicker/split-screen/black-line corruption on real hardware
-- the same class of bug `../../firmware/src/display_driver.cpp`'s header
comment documents in detail: this panel has no row-seek command in QSPI
mode and requires the *entire* frame to be written sequentially every
refresh, which Arduino_GFX's partial-rectangle writes don't respect.
`display_ui.cpp` now uses the same fix as `firmware/`: Waveshare's own
`esp_lcd`-based panel driver (proven correct on real hardware), full-frame
software rotation, and chunked DMA writes -- see `display_ui.cpp`'s own
comments for this project's specifics.

`touch/esp_lcd_touch.*` is pulled in only because `axs15231b/`'s header
depends on its types (`esp_lcd_touch_new_i2c_axs15231b()` and friends);
this project doesn't call any touch API, same as `firmware/`.

Unlike `firmware/`, this project keeps `GFX Library for Arduino` as a
`lib_deps` -- not for its (buggy, on this panel) hardware panel driver, but
purely as a headless framebuffer + bitmap-font renderer (`Arduino_Canvas`,
constructed with a `nullptr` output so it never touches real hardware). See
`display_ui.cpp`'s header comment.

Do not hand-edit `axs15231b/`/`touch/` piecemeal; if Waveshare updates their
example, re-copy wholesale from the new version instead of patching around
drift (in both this directory and `firmware/src/`).

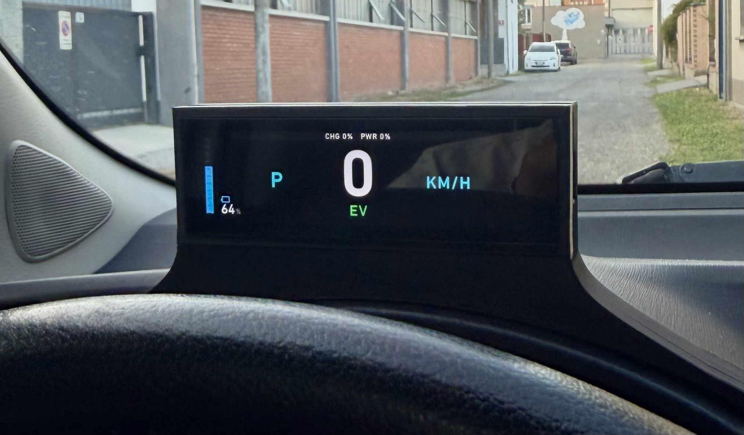
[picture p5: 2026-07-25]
firmware/sim/screenshot/screenshots/hero.png

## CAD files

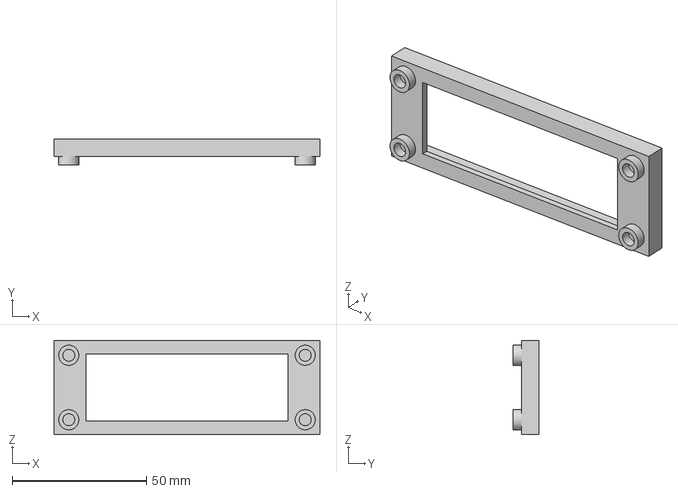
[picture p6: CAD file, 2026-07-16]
3d/DisplayHolder.3mf
99.0 x 9.50 x 35.0 mm

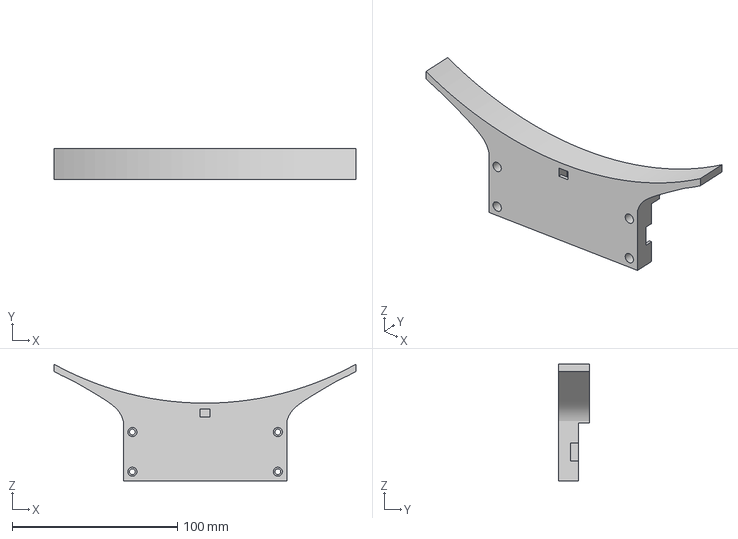
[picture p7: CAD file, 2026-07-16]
3d/DisplayCover.3mf
182.7 x 18.5 x 70.5 mm

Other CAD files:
3d/yaris-virtual-cockpit.f3d

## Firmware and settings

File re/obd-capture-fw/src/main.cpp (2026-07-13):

// obd-capture: passive CAN bus logger for the Toyota Yaris Hybrid (3rd gen).
//
// Four FreeRTOS tasks (see app_config.h for priorities/cores):
//   canRxTask     (can_capture.cpp) - TWAI listen-only RX, highest priority, core 1
//   sdWriterTask  (sd_logger.cpp)   - buffered candump-format SD logging, core 0
//   usbStreamTask (usb_stream.cpp)  - live candump stream over USB-CDC, core 0
//   displayTask   (display_ui.cpp)  - live ID table + stats bar, lowest priority, core 0
//
// canRxTask never touches SD, USB streaming, or display APIs, so an SD
// stall, a slow PC-side reader, or a slow redraw can never cause a dropped
// CAN frame.

#include <Arduino.h>
#include "app_config.h"
#include "rtc_clock.h"
#include "sd_logger.h"
#include "can_capture.h"
#include "usb_stream.h"
#include "display_ui.h"

namespace {

void handleSerialCommand(const String &line) {
    if (line.startsWith("SETTIME ")) {
        time_t epoch = strtoul(line.c_str() + 8, nullptr, 10);
        RtcClock::set(epoch);
        Serial.printf("[main] RTC set to epoch %ld\n", static_cast<long>(epoch));
    } else if (line == "STOP") {
        SdLogger::requestStop();
        Serial.println("[main] capture session stop requested");
    } else if (line == "STREAM ON") {
        UsbStream::setEnabled(true);
        Serial.println("[main] USB live stream ON -- raw candump lines follow, "
                        "send 'STREAM OFF' to return to normal console output");
    } else if (line == "STREAM OFF") {
        UsbStream::setEnabled(false);
        Serial.println("[main] USB live stream OFF");
    } else if (line.length() > 0) {
        Serial.println("[main] unknown command. Known: SETTIME <unix_epoch>, STOP, STREAM ON, STREAM OFF");
    }
}

// Compact one-line status, same fields as display_ui.cpp's stats bar, printed
// periodically so capture progress is visible over serial even when the
// display isn't working.
void printStatusLine() {
    CanCaptureStats canStats = CanCapture::getStats();
    SdLoggerStats sdStats = SdLogger::getStats();
    uint32_t upSec = millis() / 1000;

    Serial.printf("[status] %.1ff/s Bus:%.1f%% Err:%lu BusOff:%lu USBq:%lu%% SD:%s",
                  canStats.frames_per_sec, canStats.bus_load_pct,
                  static_cast<unsigned long>(canStats.bus_error_count),
                  static_cast<unsigned long>(canStats.bus_off_count),
                  static_cast<unsigned long>(canStats.usb_queue_backlog_pct),
                  sdStats.card_mounted ? (sdStats.session_open ? "open" : "mounted") : "NONE");
    if (sdStats.card_mounted) {
        Serial.printf(" %.1fGBfree Q:%lu%% session:%lu frames:%lu",
                      sdStats.free_space_gb,
                      static_cast<unsigned long>(canStats.sd_queue_backlog_pct),
                      static_cast<unsigned long>(sdStats.session_number),
                      static_cast<unsigned long>(sdStats.frames_written));
    }
    Serial.printf(" Up:%02lu:%02lu:%02lu\n",
                  static_cast<unsigned long>(upSec / 3600),
                  static_cast<unsigned long>((upSec / 60) % 60),
                  static_cast<unsigned long>(upSec % 60));
}

} // namespace

void setup() {
    Serial.begin(SERIAL_BAUD);
    delay(300); // let USB-CDC/serial monitor attach
    Serial.println("\n[main] obd-capture starting");

    RtcClock::begin();
    if (!RtcClock::isValid()) {
        Serial.println("[main] RTC not set -- send 'SETTIME <unix_epoch_seconds>' over serial to set it. "
                        "Until then, log timestamps are relative to boot, not wall-clock.");
    }

    QueueHandle_t sdQueue = SdLogger::begin();
    QueueHandle_t usbQueue = UsbStream::begin();
    CanCapture::begin(sdQueue, usbQueue);
    DisplayUi::begin();

    Serial.println("[main] all tasks started");
}

void loop() {
    if (Serial.available()) {
        String line = Serial.readStringUntil('\n');
        line.trim();
        handleSerialCommand(line);
    }

    static uint32_t lastStatusMs = 0;
    uint32_t nowMs = millis();
    // Suppressed while streaming: the live candump feed has the port to
    // itself, so a PC-side reader can capture straight to a file without
    // filtering out status lines.
    if (!UsbStream::isEnabled() && nowMs - lastStatusMs >= SERIAL_STATUS_INTERVAL_MS) {
        lastStatusMs = nowMs;
        printStatusLine();
    }

    vTaskDelay(pdMS_TO_TICKS(50));
}

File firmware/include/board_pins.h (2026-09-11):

#pragma once

#include <cstdint>

// Pin mapping for the Waveshare ESP32-S3-Touch-LCD-3.49, board silkscreen "Rev1.1".
// Onboard peripheral pins (display/RTC/SD) were extracted from Waveshare's own
// official example code (github.com/waveshareteam/ESP32-S3-Touch-LCD-3.49,
// Examples/Arduino/09_LVGL_V8_Test/user_config.h, 02_I2C_PCF85063/rtc_bsp.cpp,
// 04_SD_Card/sdcard_bsp.cpp) rather than guessed.
//
// The CAN transceiver pins were chosen from the 22-pin expansion header GPIOs
// actually confirmed present on the user's board (photographed silkscreen):
// 0, 1, 2, 3, 4, 5, 19, 20, 38, 39, 40, 41, 43, 44 (+ 3V3/BAT/G/5V/SDA/SCL).
// Excluded from consideration: GPIO0/3 (boot strapping, GPIO0 already wired to
// the BOOT button), GPIO19/20 (native USB D-/D+ -- shares the USB-C port used
// for flashing/serial monitor, do NOT repurpose), GPIO39/40/41 (already used
// internally by the onboard SDMMC card slot), GPIO43/44 (UART0, used by the
// USB-serial bridge for flashing/serial monitor), SDA/SCL (GPIO47/48, already
// used internally for the RTC/IMU I2C bus -- also electrically incompatible
// with the CAN transceiver's digital TX/RX signaling anyway).

// --- AXS15231B display, QSPI ---
// virtual-cockpit drives this via ESP-IDF's esp_lcd component directly
// (SPI3_HOST, see src/display_driver.cpp), not Arduino_GFX/SPI2_HOST as
// obd-capture does -- LCD_ROTATION below is unused here, this project always
// rotates the frame in software instead (see display_driver.cpp for why).
constexpr int PIN_LCD_QSPI_CS   = 9;
constexpr int PIN_LCD_QSPI_SCK  = 10;
constexpr int PIN_LCD_QSPI_D0   = 11;
constexpr int PIN_LCD_QSPI_D1   = 12;
constexpr int PIN_LCD_QSPI_D2   = 13;
constexpr int PIN_LCD_QSPI_D3   = 14;
constexpr int PIN_LCD_RESET     = 21;
constexpr int PIN_LCD_BACKLIGHT = 8;

constexpr int LCD_PANEL_NATIVE_WIDTH  = 172; // physical panel width (portrait)
constexpr int LCD_PANEL_NATIVE_HEIGHT = 640; // physical panel height (portrait)
constexpr int LCD_ROTATION = 1;              // rotate to landscape 640x172 for the UI

// --- Shared sensor I2C bus (PCF85063 RTC + QMI8658 IMU) ---
// The IMU half is live: src/imu.cpp drives the QMI8658's accelerometer over
// Wire1 for the G-meter screen. The RTC is still unread. This is a
// *different* I2C bus from the capacitive touch controller below, which
// touch_nav.cpp owns via Wire.
constexpr int PIN_SENSOR_I2C_SDA = 47;
constexpr int PIN_SENSOR_I2C_SCL = 48;
constexpr uint8_t I2C_ADDR_RTC_PCF85063 = 0x51;
constexpr uint8_t I2C_ADDR_IMU_QMI8658 = 0x6B;

// --- Capacitive touch (AXS15231B, same die as the display panel) ---
// Read directly over I2C via touch_nav.cpp (plain Arduino Wire, not the
// vendored esp_lcd_touch component -- see that file's header comment for
// why). Screens cycle on any tap, same action as the BOOT button.
constexpr int PIN_TOUCH_SDA = 17;
constexpr int PIN_TOUCH_SCL = 18;

// --- microSD card, native SDMMC 1-bit mode (NOT SPI) ---
constexpr int PIN_SD_CMD = 39;
constexpr int PIN_SD_CLK = 41;
constexpr int PIN_SD_D0  = 40;

// --- 22-pin expansion header: CAN transceiver (SN65HVD230) ---
// RS pin on the SN65HVD230 breakout should be wired directly to GND (always
// high-speed mode). Leave the breakout's onboard 120-ohm termination jumper
// OPEN/disabled -- the vehicle's OBD-II bus is already terminated at both ends.
constexpr int PIN_TWAI_TX = 1; // ESP32 GPIO1 -> SN65HVD230 "TX" (D input)
constexpr int PIN_TWAI_RX = 2; // ESP32 GPIO2 <- SN65HVD230 "RX" (R output)

// --- Physical BOOT button, used here to cycle screens (see screen_nav.h) ---
constexpr int PIN_BOOT_BUTTON = 0; // active LOW

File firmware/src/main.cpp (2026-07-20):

// virtual-cockpit: LVGL instrument cluster for the Toyota Yaris Hybrid
// (3rd gen / XP130). Two FreeRTOS tasks (see include/app_config.h):
//   canRxTask (can_decoder.cpp) - TWAI listen-only RX + DBC decode, core 1
//   lvglTask  (display_driver.cpp) - LVGL rendering, core 0
//
// Build with `pio run -e demo` (DEMO_FAKE_DATA) to sweep the UI through
// fake values with no TWAI/vehicle connection at all. Normal builds
// (`pio run`) use live CAN.

#include <Arduino.h>
#include "app_config.h"
#include "can_decoder.h"
#include "display_driver.h"

void setup() {
    Serial.begin(SERIAL_BAUD);
    delay(300); // let USB-CDC/serial monitor attach
    Serial.println("\n[main] virtual-cockpit starting");

#ifdef DEMO_FAKE_DATA
    Serial.println("[main] DEMO_FAKE_DATA build -- no CAN/vehicle connection needed");
#endif

    CanDecoder::begin();
    DisplayDriver::begin();

    Serial.println("[main] all tasks started");
}

void loop() {
    vTaskDelay(pdMS_TO_TICKS(50));
}

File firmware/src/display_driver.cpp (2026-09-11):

#include "display_driver.h"
#include "board_pins.h"
#include "app_config.h"
#include "can_decoder.h"
#include "ui/app_ui.h"
#include "screen_nav.h"
#include "touch_nav.h"
#include "g_meter.h"
#include "axs15231b/esp_lcd_axs15231b.h"

#include <Arduino.h>
#include <lvgl.h>
#include "esp_heap_caps.h"
#include "esp_timer.h"
#include "freertos/task.h"
#include "freertos/semphr.h"
#include "driver/gpio.h"
#include "driver/spi_master.h"
#include "esp_lcd_io_spi.h"
#include "esp_lcd_panel_io.h"
#include "esp_lcd_panel_ops.h"
#include "esp_lcd_panel_vendor.h"

// Drives the AXS15231B over QSPI via ESP-IDF's esp_lcd component + Waveshare's
// own panel driver (ported verbatim into src/axs15231b/, src/touch/,
// src/lcd_bl_bsp/ from their official 09_LVGL_V8_Test/10_LVGL_V9_Test
// examples), NOT Arduino_GFX.
//
// Why: this panel, in QSPI mode, has no row-seek command -- panel_axs15231b
// _draw_bitmap() deliberately never sends RASET when use_qspi_interface=1.
// Its RAMWR/RAMWRC protocol only supports writing the *entire* frame,
// sequentially, top-to-bottom, every time (RAMWR resets the internal write
// pointer to the top, RAMWRC continues from wherever it currently is).
// Arduino_GFX's generic AXS15231B driver doesn't know this and happily
// issues arbitrary partial-rectangle writes -- exactly what LVGL's default
// partial-refresh flush does -- which desyncs the panel's internal write
// pointer. That is what produced the flicker/split-screen/black-line
// corruption on real hardware (both here and in obd-capture, which used the
// same Arduino_GFX approach).
//
// The fix, matching Waveshare's own official example byte-for-byte:
// `full_refresh=1` (LVGL always hands the flush callback the complete
// frame) and drive the panel in its native 172(w)x640(h) portrait
// orientation, rotating the full landscape frame into a native-orientation
// scratch buffer in software before streaming it out in fixed-size DMA
// chunks -- there is no working hardware-rotation path for this panel on
// this board revision (Waveshare's own comment for this: "软件实现旋转",
// "software-implemented rotation").
namespace {

// --- Native (physical) vs logical (LVGL/UI) orientation ---
constexpr int kNativeW = LCD_PANEL_NATIVE_WIDTH;  // 172, physical panel width
constexpr int kNativeH = LCD_PANEL_NATIVE_HEIGHT; // 640, physical panel height
constexpr int kLogicalW = kNativeH; // 640, LVGL/UI landscape width
constexpr int kLogicalH = kNativeW; // 172, LVGL/UI landscape height

constexpr int kChunkRows = 64; // native rows per DMA chunk, matches Waveshare's example
static_assert(kNativeH % kChunkRows == 0, "kNativeH must divide evenly into kChunkRows-sized chunks");
constexpr int kChunkCount = kNativeH / kChunkRows;
constexpr size_t kDmaChunkBytes = static_cast<size_t>(kNativeW) * kChunkRows * sizeof(uint16_t);
constexpr size_t kFullFrameBytes = static_cast<size_t>(kLogicalW) * kLogicalH * sizeof(uint16_t);

esp_lcd_panel_handle_t g_panel = nullptr;
SemaphoreHandle_t g_flushSem = nullptr;

uint16_t *g_dmaChunkBuf = nullptr;    // small, MALLOC_CAP_DMA, internal RAM
uint16_t *g_nativeFrameBuf = nullptr; // full native-orientation frame, PSRAM scratch

lv_disp_draw_buf_t g_drawBuf;
lv_disp_drv_t g_dispDrv;
lv_color_t *g_buf1 = nullptr;
lv_color_t *g_buf2 = nullptr;

esp_timer_handle_t g_tickTimer = nullptr;

bool IRAM_ATTR onColorTransDone(esp_lcd_panel_io_handle_t, esp_lcd_panel_io_event_data_t *, void *) {
    BaseType_t taskWoken = pdFALSE;
    xSemaphoreGiveFromISR(g_flushSem, &taskWoken);
    return taskWoken == pdTRUE;
}

// Rotates the full LVGL landscape frame (kLogicalW x kLogicalH) into the
// panel's native portrait orientation (kNativeW x kNativeH), pixel-for-pixel
// identical to Waveshare's own transpose (see the file header comment).
void rotateToNative(const uint16_t *landscape, uint16_t *native) {
    uint32_t index = 0;
    for (int j = 0; j < kLogicalW; j++) {
        for (int i = 0; i < kLogicalH; i++) {
            native[index++] = landscape[kLogicalW * (kLogicalH - i - 1) + j];
        }
    }
}

void dispFlush(lv_disp_drv_t *disp, const lv_area_t *area, lv_color_t *color_p) {
    // full_refresh=1 guarantees area always covers the whole screen and
    // color_p always holds the complete current frame.
    (void)area;
    rotateToNative(reinterpret_cast<const uint16_t *>(color_p), g_nativeFrameBuf);

    int offsetY1 = 0;
    int offsetY2 = kChunkRows;
    const uint16_t *src = g_nativeFrameBuf;

    xSemaphoreGive(g_flushSem); // prime the first iteration
    for (int i = 0; i < kChunkCount; i++) {
        xSemaphoreTake(g_flushSem, portMAX_DELAY);
        memcpy(g_dmaChunkBuf, src, kDmaChunkBytes);
        esp_lcd_panel_draw_bitmap(g_panel, 0, offsetY1, kNativeW, offsetY2, g_dmaChunkBuf);
        offsetY1 += kChunkRows;
        offsetY2 += kChunkRows;
        src += kNativeW * kChunkRows;
    }
    xSemaphoreTake(g_flushSem, portMAX_DELAY); // wait for the last chunk to finish
    lv_disp_flush_ready(disp);
}

void IRAM_ATTR onLvglTick(void *) {
    lv_tick_inc(LVGL_TICK_PERIOD_MS);
}
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

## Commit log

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2026-07-08 Fix virtual-cockpit compile errors found on first real pio run
    - lv_conf.h: drop LV_MEM_POOL_INCLUDE/LV_MEM_POOL_ALLOC -- defining
    them (even empty) makes lv_mem.c take the custom-pool #include path,
    which needs a real filename. The stock template #undefs these;
    omitting them entirely is correct.
    - bar_gauge.h: create()'s first parameter was named `h`, colliding
    with the `int16_t h` height parameter later in the same signature.
    Renamed to `hd` to match the .cpp definition.
    Found and fixed on the owner's own machine with a working ESP32
    toolchain, which this sandbox never had access to.
    Claude-Session: https://claude.ai/code/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
2026-07-08 Replace Arduino_GFX with Waveshare's own esp_lcd AXS15231B driver
    Root cause of the flicker/split-screen/black-line corruption reported
    on real hardware (and, per the owner, the same reason obd-capture's
    display never worked visually either): this panel, in QSPI mode, has
    no row-seek command -- its RAMWR/RAMWRC protocol only supports writing
    the entire frame sequentially, top-to-bottom, every refresh. Arduino_GFX's
    generic AXS15231B driver doesn't know this and issues arbitrary
    partial-rectangle writes (LVGL's default partial-refresh behavior),
    desyncing the panel's internal write pointer.
    Ports Waveshare's own official example (Arduino/10_LVGL_V9_Test) instead
    of Arduino_GFX: esp_lcd_panel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
    [board_pins.h, display_driver.cpp]
2026-07-08 Fix missing text and wrong colors reported on real hardware
    - LV_USE_FONT_COMPRESSED 0 -> 1: lv_font_conv's default output is
    RLE-compressed (bitmap_format=1 in every generated font .c), but the
    decompressor wasn't compiled in, so every glyph silently failed to
    decode -- combined with LV_USE_FONT_PLACEHOLDER=1 (draw nothing for
    undecodable glyphs), this made all text render as blank.
    - LV_COLOR_16_SWAP 0 -> 1: this panel expects big-endian RGB565 over
    QSPI (like virtually all SPI/QSPI TFT controllers), but LVGL's buffer
    holds pixels in native little-endian order by default. Verified by
    hand against the RGB565 bit math that this exactly explains the
    reported color shifts (bg #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
2026-07-08 Tune cockpit UI layout per owner feedback
    - Gear letter: bigger font (32px -> 40px), same position.
    - Units label ("KM/H"): untouched, as requested.
    - RPM/EV row: bigger font (18/20px -> 26/28px), and re-centered as one
    block together with the speed number (speed moves up slightly,
    dy=+4->-14; RPM/EV moves closer, dy=+58->+48), with a deliberate 10px
    gap computed from the fonts' actual line_height metrics instead of
    the cramped ~12px gap the original fixed anchors produced.
    - HV battery gauge: bar extended down to a 6px margin from the bottom
    edge (was stopping well short at y=140 of 172) and up slightly
    (y=30->22); the icon + numeric readout moved from the top of the
    column to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
2026-07-08 Fix battery gauge and speed/RPM-EV block margins per feedback
    - Battery gauge: symmetric 16px top/bottom margin (was 22/6, which read
    as "too far down") -- bar now spans y=16..156 instead of 22..166.
    - Speed + RPM/EV block: widened the gap between them from 10px to 22px
    (was "RPM/EV too close to speed") while re-centering the whole block
    so the margin above speed equals the margin below RPM/EV (~22-23px
    each), which also shrinks the excess empty space that was left at the
    bottom.
    Claude-Session: https://claude.ai/code/session_01KLx73b1WcrAjYTGNZREarr
2026-07-09 Fix speed-to-CHG/PWR-bar spacing; mirror left slot onto the battery layout
    - Speed/RPM-EV block: re-anchored between the CHG/PWR bar's bottom edge
    (y=16) and the screen bottom (y=172) instead of the raw screen
    midpoint, so the gap above speed now equals the gap below the RPM/EV
    row (~14.5px each) -- speed was sitting right under the bar.
    - Left slot (ambient temp + clock) now mirrors the battery gauge's
    layout: temperature sits in the same row as the battery icon, clock
    in the same row as the battery's numeric value (bottom-aligned with
    the bar), both promoted from 18px to 26px (dinnext_26_rpm, reused
    from the RPM row -- same glyph set already covers digits/:/°/C).
    - Demo buil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
    [display_driver.cpp]
2026-07-09 Tighten speed/RPM-EV gap, fix clock color and temp/clock spacing
    - Speed-to-RPM/EV gap: ~22-23px -> ~17px (speed dy=-11, RPM/EV dy=+58),
    per owner feedback.
    - Left-slot clock: was Colors::kMutedText (gray) -- now Colors::kText
    (white), matching the temperature label above it.
    - Left-slot temperature: was reusing kSideIconY (tuned for the battery
    icon's 12px height), which put a 19px-tall text label almost flush
    against the clock row below it. Gave it its own kLeftTempY with a
    proper 4px gap sized for its actual text height instead.
    Claude-Session: https://claude.ai/code/session_01KLx73b1WcrAjYTGNZREarr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
2026-07-09 Swap sides: battery gauge to the left, temperature/clock to the right
    - HV battery bar + icon + numeric readout moved to the left column
    (x=18..92): tick gauge flush to the column's outer/left edge, icon/
    nub/value on the inner side toward screen center (mirrors the
    original right-column arrangement).
    - Ambient temperature + clock moved to the right column (x=548..622),
    right-aligned (not centered) so both lines share a common right edge.
    - Renamed createLeftSlot -> createTempClockSlot and g_left* -> g_temp/
    g_clock labels to match their new position.
    Co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
2026-07-09 Trim demo log lead-in: start playback at the first gear change out of P
    The recorded session (data/logs/session_0047.log) opens with the car
    parked in P for ~99s before the driver pulls away, so every loop of the
    demo build sat at 0km/h/P for the first ~100s of its 440s cycle -- easy to
    mistake for a stuck playback on the bench. gen_demo_log.py now finds the
    first frame where GEAR_PACKET leaves P and drops everything before it, so
    the embedded log (and the loop point) starts from there instead. Cuts
    23283 lead-in frames; the loop is now 341.3s instead of 440s.
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2026-07-09 Add SDL2 desktop simulator; fix real ESP_LCD_TOUCH_IO_I2C_AXS15231B_CONFIG_EX build error
    sim/: a CMake project reusing the actual UI sources (cockpit_ui,
    energy_flow_ui, flow_arrow, bar_gauge, app_ui, fonts) and the real demo-log
    replay (can_decoder.cpp + demo_log_data.cpp, DEMO_FAKE_DATA) against an
    SDL2 window instead of the QSPI panel/TWAI, with mouse click-drag standing
    in for a touch swipe -- lets the UI be tested on a Mac without flashing.
    LVGL is fetched via CMake FetchContent pinned to the same 8.3.11 the
    firmware build uses, sharing this project's own include/lv_conf.h so both
    builds render identically (in particular LV_COLOR_16_SWAP, which the SDL
    flush_cb has to undo since SDL's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
2026-07-09 Add touch read diagnostics to narrow down why touch isn't responding
    Real hardware test: firmware boots fine, "[touch_input] AXS15231B touch
    indev registered" prints, but touching the panel does nothing. Since
    touch_axs15231b_read_data() uses ESP_RETURN_ON_ERROR (which logs on I2C
    failure) and no such log appeared, the I2C transactions are likely
    succeeding at the driver level -- the ignored return value and the lack of
    any visibility into what coordinates/pressed-state the chip is actually
    reporting made this impossible to narrow down further blind. Logs I2C read
    failures (throttled) and, when a touch is detected, the resulting LVGL
    point coordinates (throttled while dragging), so the next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
2026-07-09 Rewrite touch bring-up from Waveshare's real reference; fix energy-tile lag
    touch_input.cpp: real hardware test confirmed touch produced no response at
    all with the esp_lcd_touch/esp_lcd_panel_io_i2c approach. The user supplied
    Waveshare's actual working example (Arduino/09_LVGL_V8_Test/lvgl_port.c +
    i2c_bsp.c, which matches this project's own vendored i2c_bsp.c byte-for-byte)
    -- it doesn't use the esp_lcd_touch driver at all, just a raw combined I2C
    write+read on a plain i2c_master_dev_handle_t with a specific command byte
    sequence. Rewrote touch_input.cpp to match that proven approach instead.
    Also corrects the coordinate transform: their reference's axis identification
    (raw "X" = the pane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
2026-07-09 Throttle energy-flow arrow animation redraw to fix reported lag
    Real hardware test: swipe transitions ran at ~0.5fps and the energy-flow
    tile itself lagged heavily once visible. FlowArrow::tick() re-rasterizes a
    canvas pixel-by-pixel per call, and running that for up to 4 arrows at the
    full ~30Hz AppUi::update() rate (both while resting on the tile and, since
    scroll_x != 0 as soon as a drag starts, throughout the swipe transition
    itself) was the direct cause. Direction/color changes (setState()) stay
    fully responsive every call -- those are rare and cheap regardless -- only
    the continuous flow animation itself is now redrawn at ~6-7Hz instead of
    ~30Hz, choppier motion in exchange for the til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
    [energy_flow_ui.cpp]
2026-07-09 Drop touch/swipe entirely, switch screens with the BOOT button instead
    Real hardware test: even after throttling the energy-flow animation redraw
    rate, both the tileview swipe transition and the energy-flow tile itself
    were still reported laggy. Per the user's direction, touch is dropped
    entirely rather than chased further -- screen switching now goes through
    the board's BOOT button (PIN_BOOT_BUTTON, GPIO0) with a debounced edge
    read (screen_nav.cpp), toggling between two plain full-screen containers
    via an instant LV_OBJ_FLAG_HIDDEN flip (no scroll animation of any kind).
    Deleted touch_input.h/.cpp and reverted LV_USE_TILEVIEW to 0 -- neither is
    used anymore. EnergyFlowUi::update() is now o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
    [display_driver.cpp, energy_flow_ui.cpp]
2026-07-09 Redesign energy-flow screen layout: white labels, 90-degree engine-wheels corner
    - Node labels now use Colors::kText (white) instead of Colors::kMutedText
    (gray), per the requested design pass.
    - flow_arrow.{h,cpp}: adds FlowArrow::createBent() for a 90-degree bent
    path (two segments joined at an elbow, animated/arrowed as one
    continuous path -- the arrowhead only ever sits at the overall head end,
    never at the corner). ENGINE-WHEELS now uses this instead of a diagonal
    line: straight down from ENGINE to WHEELS' row, then straight across.
    - Moved ENGINE (x=100->170) and BATTERY (x=555->470) inward toward MOTOR,
    evenly spaced (150px between each pair of centers, was 225-230px and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
    [energy_flow_ui.cpp]
2026-07-10 Energy-flow design pass 2: fix bent-arrow corner, side labels, live %, icons
    Fixes the red ENGINE->WHEELS arrow rendering "cut in half": in
    flow_arrow.cpp redrawBent(), each shaft now overshoots the elbow centreline
    by half a thickness (shaftHiA += thickness/2, shaftLoB -= thickness/2), so
    the outer corner of the L fills solid instead of leaving a ~5px background
    notch that read as a break on the panel.
    Typography: generated a new DIN Next Bold 24px subset with the full
    uppercase alphabet (dinnext_24_label.c, via the existing gen_fonts.sh
    tooling + the committed bold OTF) -- the node words previously used
    Montserrat 14 because no DIN font carried letters. Labels are now this 24px
    DIN, white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
    [energy_flow_ui.cpp]
2026-07-10 Move WHEELS label to the right of the wheel
    Per feedback: the WHEELS label reads better on the right (empty) side of the
    wheel, symmetric with the ENGINE label sitting left of its icon. The
    ENGINE->WHEELS arrow now enters the wheel's left edge at its vertical centre
    again (no longer dodging a left-side label).
    Claude-Session: https://claude.ai/code/session_011fDBYCnEyysWZHmi1vkrmL
    [energy_flow_ui.cpp]
2026-07-10 Energy-flow: fix BATTERY label wrap; redraw engine/motor as check-engine + bolt
    - BATTERY label was wrapping ("BATTER" / "Y") because the node labels had a
    fixed 96px width and "BATTERY" at 24px DIN is wider. Labels are now
    content-sized (single line, no wrap) and positioned by measured text width
    via lv_txt_get_size, anchored left/centre/right per node.
    - Reworked the ENGINE and MOTOR icons into the classic check-engine (MIL)
    silhouette (clean blocks + a rounded right bell housing) per the reference
    photo. The MOTOR is the SAME silhouette in cyan with a lightning bolt
    punched through the body (new fillPoly scanline helper), reading as
    "engine, but electric" -- and now clearly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
    [energy_flow_ui.cpp]
2026-07-10 Energy-flow icons: restore engine block; motor = same block, no fins, + bolt
    Per feedback the check-engine silhouette was disliked. Reverted ENGINE to
    the earlier engine-block icon (body + cylinder stubs + belt pulley + cooling
    fins). MOTOR is now that same block minus the fins, with a lightning bolt
    punched through the body -- reads as "engine, but electric".
    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
    [energy_flow_ui.cpp]
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2026-07-10 Add hybrid-efficiency screen (3rd screen, cycled by BOOT button)
    New session-stats module + screen showing how the drive is going, all
    derived from the already-decoded signals (no new CAN work):
    - hybrid_stats.{h,cpp}: integrates VehicleState every UI tick into session
    totals (distance, EV-vs-engine distance split, regen time, moving time,
    max/avg speed, SOC range). "Session" == since power-on, which on a
    car-powered cluster naturally coincides with the start of a drive, so it
    resets on its own each start. Guards against the pre-first-frame 0 defaults
    (SOC, dt).
    - ui/efficiency_ui.{h,cpp}: an EV | ENGINE split bar (lv_bar: green EV
    indicator over a red engine track, crisp bounda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
2026-07-13 Add live CAN log streaming over USB for debug/new-feature work
    Adds a usbStreamTask (own queue, fan-out from canRxTask alongside the
    existing SD writer) that streams every captured frame over the same
    USB-CDC port in candump format, toggled with STREAM ON/OFF serial
    commands and off by default so it never interferes with SD logging.
    Also adds tools/usb_stream_logger.py to capture the stream straight to
    a file on a PC for further analysis.
    Claude-Session: https://claude.ai/code/session_01PwC9X1ZvAx5JhrETeEwjKb
    [app_config.h, can_capture.cpp, main.cpp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]
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2026-07-14 Fix road-test bugs: temp/clock display, RPM=0 EV, CHG/PWR sign-wrap
    - Remove the ambient-temperature and clock readouts from the cluster.
    0x442 is outside air temperature, not engine/coolant temp (no
    confirmed coolant signal is wired into the firmware), so it was
    showing the wrong thing; the clock was an explicit removal request.
    Also drops the now-orphaned RTC module (rtc_clock.*, SETTIME command).
    - Force the RPM/EV row to show "EV" whenever RPM reads 0 (e.g. at boot
    before any CAN traffic), instead of leaving "RPM 0" on screen. The
    raw ev_drive/ice_running CAN bits are untouched -- display-only fix.
    - Fix a sign-wrap bug in the CHG/PWR (HSI) decode: 0x247 byte[1] was
    cast st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
    [can_decoder.cpp, display_driver.cpp, main.cpp]
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2026-07-14 Cycle screens with the steering-wheel MODE button (0x4AC)
    Reverse-engineered from a targeted capture (3 bursts of 5 rapid taps,
    ~5s apart, car stationary): CAN ID 0x4AC byte[6] is 0x03 while idle
    and 0xD3/0xB3 (alternating) while the MODE button is pressed/held,
    with bits 4+7 (mask 0x90) reliably set in both. The signal doesn't
    isolate individual taps within a burst, but a plain rising-edge
    trigger matches the physical BOOT button's existing UX for normal,
    deliberately-spaced presses.
    AppUi now cycles screens on either the BOOT button or a MODE-button
    rising edge. can_decoder.cpp only decodes the raw flag; edge detection
    lives in app_ui.cpp, same separation as the existing ScreenNav-driven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
    [can_decoder.cpp]
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2026-07-14 Harden MODE button (0x4AC) screen cycling against press loss
    Road testing showed unreliable screen cycling from the steering-wheel
    MODE button. Re-analysis of the only capture quantifies why: the ECU
    latches byte[6] active ~2s after each press (retriggered per tap), so
    presses closer than ~2.5s apart merge into a single idle->active edge
    and can only cycle one screen -- a property of the signal, not the
    firmware. The D3/B3 alternation open question is also resolved: it is
    phase-locked to the rolling counter in byte[4] (zero exceptions across
    the capture) and carries no per-tap information.
    Firmware hardening (none of which can un-merge close presses, but
    removes every loss mode the firmware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
    [app_config.h, can_decoder.cpp]
2026-07-15 Retract MODE button finding: 0x4AC byte[6] is a free-running oscillator
    Second road test showed the screens cycling BY THEMSELVES at constant
    intervals. Cross-checking 0x4AC byte[6] against the two real-drive logs
    (button never touched there) explains everything: it is a free-running
    square wave -- 9 frames at 0x03, 9 frames at 0xB3/0xD3, 4.5s/4.5s, 9.0s
    period, phase-locked to the byte[4] rolling counter -- running
    identically in all three logs. One rising edge every 9s = one phantom
    screen cycle every 9s. In the dedicated capture, the 'initial blip' was
    a truncated active half-wave and the '3 tap bursts' were simply the
    next 3 active half-waves: a 31s capture of a 9s square wave is
    indisti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
    [app_config.h, can_decoder.cpp]
2026-07-15 Add sw-capture: ESP32-C3 ADC logger for the steering-switch ladder
    New third PIO project (sw-capture/) to characterize the steering-wheel
    switch resistive ladder -- the real home of the MODE button after the
    CAN retraction. Targets a separate ESP32-C3 mini/SuperMini board so the
    cluster S3 stays untouched while probing the car.
    Firmware (single paced loop, 1kHz median-of-5 on GPIO3/ADC1_CH3,
    calibrated millivolts):
    - EVT lines, always on: debounced stable-level changes with timestamp,
    previous/new level and dwell time -- pressing each button once makes
    the ladder table fall straight out of the log
    - LVL heartbeat every 5s so bias drift is visible with no activity
    - optional CSV stream (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
    [app_config.h, main.cpp]
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2026-07-19 Remove the MODE-button pursuit; add tap-anywhere touch navigation
    Applied on top of the concurrent structure refactor (virtual-cockpit/ ->
    firmware/, docs/tools/obd-capture -> re/) and docs cleanup that landed on
    main from other sessions/collaborators while this work was in progress.
    That cleanup pass had already translated re/docs/*.md to English and
    trimmed the DBC, but kept re/sw-capture-fw/ (renamed + rewritten README)
    as the recommended path to read the button. Live hardware debugging
    this session showed the ladder doesn't work either (no voltage change
    on any of the SW1/SW2/SWG pins tried, for reasons not yet root-caused)
    -- per explicit instruction, every remaining trace of the MODE-b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
    [app_config.h, board_pins.h, can_decoder.cpp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]
2026-07-20 Code cleanup: fix stale comments and dead code
    - Fix gen_demo_log.py: broken imports/paths from the tools/ and data/
    move into re/ (ModuleNotFoundError on run)
    - Fix on-device Italian string in obd-capture-fw's ID table display
    - Fix board_pins.h BOOT-button comment copy-pasted from obd-capture-fw
    (wrong here: this firmware uses it for screen nav, not capture control)
    - Remove a no-op ternary in bar_gauge.cpp (both branches were identical)
    - Trim task-history framing ("per owner feedback", dangling "plan doc"
    references) from comments in cockpit_ui.cpp, energy_flow_ui.cpp,
    colors.h, gen_fonts.sh, and synth_bold.py, keeping the underlying
    design rationale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
    [board_pins.h, display_ui.cpp, energy_flow_ui.cpp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]
2026-07-21 obd-capture-fw: replace Arduino_GFX panel driver with firmware's esp_lcd driver
    Arduino_GFX's generic AXS15231B driver issues partial-rectangle writes the
    panel can't handle correctly over QSPI (no row-seek command in QSPI mode),
    producing flicker/split-screen/black-line corruption on real hardware --
    already documented as the root cause of firmware/'s own display bug, and
    called out there as affecting obd-capture-fw too.
    Ports firmware/'s proven fix: Waveshare's own esp_lcd-based panel driver
    (axs15231b/, touch/, copied verbatim, see the new WAVESHARE_VENDORED.md),
    full-frame software rotation, and chunked DMA writes. GFX Library for
    Arduino stays as a dependency, but now only for Arduino_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
    [board_pins.h, display_ui.cpp]
2026-07-22 Fix phantom screen cycle at boot: match Waveshare's touch read exactly
    At boot the cluster jumped from cockpit to energy-flow within a second
    and touch otherwise didn't work. Cause: touch_nav.cpp's I2C read of the
    AXS15231B diverged from Waveshare's own working LVGL_V8 example
    (09_LVGL_V8_Test/lvgl_port.c, example_lvgl_touch_cb) in three ways, each
    able to produce a stuck-"touched" reading that fires exactly one screen
    cycle on the debounced rising edge and then latches:
    1. Presence test was `point_count >= 1`; the reference is
    `buff[1] > 0 && buff[1] < 5`. An idle/floating I2C bus reads 0xFF for
    the count byte, which `>= 1` accepts as a permanent touch but the
    1..4 range correctly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
    [touch_nav.cpp]
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2026-08-30 Stop an unknown HSI zone flipping full PWR into full CHG
    Hard acceleration still swung the gauge to CHG, now the moment the bar
    passed ~64%. 179bb09 moved that threshold (raw 156 -> raw 128) without
    removing it: it derived the sign from HSI_ZONE for the three zones the
    captures contain, but left an unrecognized zone falling through to the
    DBC-nominal signed read. That read turns any raw>=128 into a large
    negative, and raw 128 is exactly 64% once the display's 0.5 PWR scale is
    applied -- which is the symptom, to the percentage point.
    The captures cannot say which zone the car reports under hard PWR: across
    both sessions (n=34109) zone 12 never exceeds raw 94 and the band raw
    95-155 appears i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
    [can_decoder.cpp]
2026-09-02 Survey HSI byte[0] properly -- the four-zone model is wrong
    The first hard-acceleration drive reported zones 8, 9 and 14 on top of the
    4/6/12/15 the captures contain. Both dbc/ and re/docs/signal_findings.md
    state that four-value set as exact across n=32779 with zero exceptions; it
    is exact for those logs and wrong for the car, because neither session
    contains the driving that produces the other values.
    The previous probe logged one frame per zone, which was built for the
    question "which zone appears at hard PWR" and cannot answer the question
    that actually turned up: what byte[0] encodes at all. Replace it with a
    survey of the real joint distribution -- frames and raw min/max per byte[0]
    v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
    [can_decoder.cpp]
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2026-09-11 Bring the README up to date with the four screens
    The README still described three screens, showed the efficiency screen's old
    four-tile layout, and said nothing about the G-meter. Everything it claimed
    about the two redesigned screens was also wrong -- the efficiency section
    listed regen % and max speed, which that screen no longer shows.
    02_energy_flow.png and 03_efficiency.png are re-rendered from the current UI,
    04_gmeter.png is new, all at the panel's native 640x172. The efficiency frame
    comes off a longer simulated drive (2.0 km, 72% electric, 70 km/h average)
    because the short scenarios only cover a hundred metres, which reads as a bug
    rather than as a short trip. 01_cockpit.png is u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
    [board_pins.h, imu.cpp]
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
